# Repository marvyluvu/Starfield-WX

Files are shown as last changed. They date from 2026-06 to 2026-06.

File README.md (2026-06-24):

<h1 align="center">StarField WX</h1>

starfield

<p align="center">
  <i>Portable Arduino‑powered dew‑risk weather station with LCD and LED halo.</i>
</p>

---

##  1. What is STARFIELD WX?

<p>
Starfield WX is a pocket-sized weather station that tells you when dew is about to become a problem for stargazing/ astrophotography.
</p>

---

##  2. Why did I make it?

<p>
I love being outside with my telescope, but because of where I live, I always end up with dew messing up my session before I could photograph anything. Starfield WX is my companion project for ORBTIZ. it can warn you about dew forming before it ruins your session.

---

##  3. How does it work?

The brains of the operation is the arduino uno. It:
- Reads temperature and humidity from a DHT11 module.
- Calculates an approximate dew point from those readings.
- Classifies dew risk (LOW, MEDIUM, HIGH) based on the spread between temperature and dew point.
- Shows live values on a 16×2 character LCD while auto‑cycling between temperature, humidity, and dew‑point screens.
- Uses a WS2812B LED halo as a status ring: green for low risk, orange for medium, red when dew is imminent.

---

##  4.Hardware schematic

<p>
You can view the full schematic for the ORBITZ PCB below.

The custom STARFIELD pcb plugs directly onto an Arduino Uno and breaks out all parts needed for weather station
</p>

key pins:
-  DHT11 data -> Arduino digital pin 2
-  WS2812B LED strip -> Arduino digital pin 6
-  1602 LCD (parallel) -> Arduino digital pins 7–12
-  Trimmer potentiometer -> LCD contrast
-  series resistors for the LCD backlight and LED strip data line

you can view the full schematic here.
STARFIELD schematic

---

##  5. How do you use it?

Power on the arduino uno via USB or a **5v** supply ( you can also power it using the usb hub on orbitz!!)

StarField WX boots, then starts cycling through three screens on the LCD:
  - Temperature in C
  - Relative humiditry in %
  - Dew point in C

The led halo color shows dew risk : green (low), orange ( medium), red (high).
when it turns red, conditions are close to the dew point and you should protect your optics or wrap up the session , unfortunately :( 

---
## 6. Assembly
Below is what the fully assembled design should look like.
1. Order all parts from the Starfield BOM.
2. Solder headers, resistors, the DHT11 module connector, LCD header, LED Strip header to the PCB.
3. Mount the potentiometer and adjust until the LCD text is clearly visible.
4. Attach the 1602 LCD to the enclosure using standoffs.
5. Cut the ws2812b strip to length and mount it arond the inside the top of the enclosure, then wire it to 5v, GND, and the data pin.
6. Insert the shield onto the Arduino Uno and secure the PCB into the enclosure.
7. Upload the code and enjoy!!

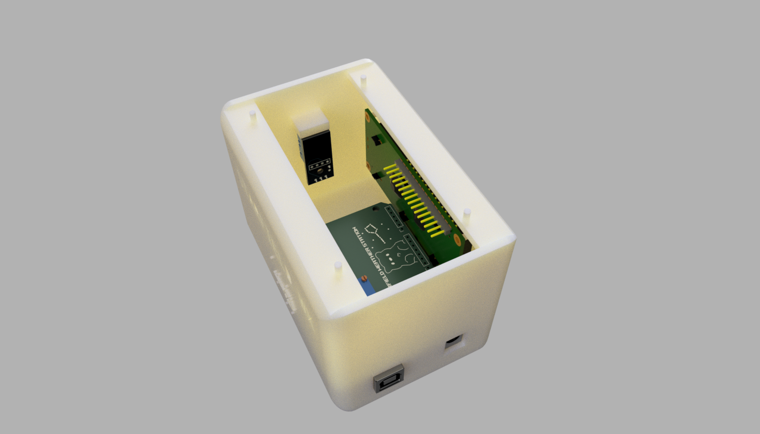
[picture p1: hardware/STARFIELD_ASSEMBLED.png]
STARFIELD enclosure interior


---

## 7. Firmware
The firmware is a single Arduino sketch that runs on the Uno

Features:

- Periodically reads DHT11 temperature and humidity
- computes dew point using a simple approximation formula
- cycle LCD screens every few seconds (temperature, humidty, dew point)
- computes dew risk catergory and updates the LED halo color

## how to flash
1. open firmware/starfield_wx.ino in the arduino IDE
2. select arduino uno as the board and choose the correct serial port
3. Install these libraries (DHT11, NEOPIXELS, LIQUID CRYSTALS) - (see [Arduino Library Installation Guide](https://docs.arduino.cc/software/ide-v1/tutorials/installing-libraries/) to know how to install libraries)
5. click upload.
6. after reseting, the splash screen appears, then live readings start
Feel free to tweak the threshold and LED colors to match your local climate and conditions

##  8. Images

<table>
  <tr>
    <td align="center">
      <strong>FINAL PCB SCREENSHOTS</strong><br><br>
      FINAL PCB SCREENSHOTS
    </td>
  </tr>
  <tr>
    <td align="center">
      <strong>PCB</strong><br><br>
      PCB
    </td>
  </tr>
  <tr>
    <td align="center">
      <strong>FINAL BUILD</strong><br><br>
      FINAL BUILD
    </td>
  </tr>
</table>

##  8. Bill of Materials (BOM)

The full detailed BOM is included in this repository:

- [[`/STARFIELD_BILL_OF_MATERIALS.csv`](https://github.com/marvyluvu/Starfield-WX/blob/69a2b140c6205f69048c935fe2e7507fc950f91d/hardware/STARFIELD_BOM.csv)

You can open this file in Excel, Google Sheets, or any spreadsheet tool.
It includes part names, descriptions, quantities, prices, and direct purchase links.

Key components

### Full BOM (summary)

### Full BOM (summary)

| Product name | Description | Qty | Unit price | Link |
|---|---|-----|---|---|
| Arduino Uno | Main microcontroller board | 1 | dh30.90 | [Amazon](https://www.amazon.ae/UNO-ATmega328P-Development-Straight-Developer/dp/B07PFCGYRS/) |
| WS2812B RGB STRIP | led halo indicator | 1 | dh3.75 | [AliExpress](https://ar.aliexpress.com/item/1005005537967685.html) |
| jumper cables | for connecting components internally | 1 | dh12.45 | [AliExpress](https://www.aliexpress.com/ssr/300000512/BundleDeals2?productIds=1005003641187997%3A12000026613929397) |
| STARFIELD custom pcb | main board | 1 | dh108.67 | JLCPCB |
| MALE HEADERS | LED , DHT11 PINS | 1 | dh3.75 | [AliExpress](https://ar.aliexpress.com/item/1005001514058091.html) |
| DHT11 MODULE | HUMIDTY AND TEMP SENSOR | 1 | dh17.48 | [AliExpress](https://ar.aliexpress.com/item/1005012263106656.html) |
| 1602A LCD Display | Main Display | 1 | dh65.88 | [Amazon](https://www.amazon.ae/naughtystarts-Character-Controller-Blacklight-Compatible/dp/B0B1QFDJ3Y/) |
| Trimmer potentiometer | Controls display contrast (3296W-103 10K) | 1 | dh10.90 | [AliExpress](https://ar.aliexpress.com/item/1005012099171886.html) |
| 220 OHM RESISTOR | lcd backlight resistor 220 OHM | 1 | dh3.75 | [AliExpress](https://ar.aliexpress.com/item/1005004002774546.html) |
| 330 OHM RESISTOR | led strip resistor 330 OHM | 1 | dh3.75 | [AliExpress](https://ar.aliexpress.com/item/1005004002774546.html) |

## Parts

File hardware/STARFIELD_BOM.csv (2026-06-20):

Product name | Product description | Quantity | Product unit price | Product Total price | Product running total. | Product link
Arduino Uno | Microcontroller | 1 | dh30.90 | dh30.90 | dh30.90 | https://www.amazon.ae/UNO-ATmega328P-Development-Straight-Developer/dp/B07PFCGYRS
Ws2812b RGB STRIP | led halo indicator | 1 | dh3.75 | dh3.75 | dh34.65 | https://ar.aliexpress.com/item/1005005537967685.html?curPageLogUid=1lvdTaLHOCXD
jumper cables | for connecting components internally | 1 | dh12.45 | dh12.45 | dh47.10 | https://www.aliexpress.com/ssr/300000512/BundleDeals2?productIds=1005003641187997%3A12000026613929397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
STARFIELD custom pcb | main board | 1 | dh108.67 | dh108.67 | dh155.77 | JLCPCB
MALE HEADERS | LED , DHT11 PINS | 1 | dh3.75 | dh3.75 | dh159.52 | https://ar.aliexpress.com/item/1005001514058091.html?curPageLogUid=lK0JHyx6snaf
DHT11 MODULE | HUMIDTY AND TEMP SENSOR | 1 | dh17.48 | dh17.48 | dh177.00 | https://ar.aliexpress.com/item/1005012263106656.html?curPageLogUid=ZAkdCPA11OTj
1602A LCD Display | Main Display | 1 | dh65.88 | dh65.88 | dh242.88 | https://www.amazon.ae/naughtystarts-Character-Controller-Blacklight-Compatible/dp/B0B1QFDJ3Y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
Trimmer potentiometer | Controls display contrast (Resistance: 3296W-103 10K 5pcs ) | 1 | dh10.90 | dh10.90 | dh253.78 | https://ar.aliexpress.com/item/1005012099171886.html?curPageLogUid=e5fHMHjDMXnP
220 OHM RESISTOR | lcd backlight resistor 220 OHM | 1 | dh3.75 | dh3.75 | dh257.53 | https://ar.aliexpress.com/item/1005004002774546.html?curPageLogUid=g365oloRU88X
330 OHM RESISTOR | led strip resistor 330 OHM | 1 | dh3.75 | dh3.75 | dh261.28 | https://ar.aliexpress.com/item/1005004002774546.html?curPageLogUid=g365oloRU88X
M3 SCREW SET | mounting pcb, screen and everything else 50 pcs 3mm | 1 | dh5.00 | dh5.00 | dh266.28 | https://ar.aliexpress.com/item/33028169759.html?curPageLogUid=FOQQuqUMxISX
m3 BRASS screw inserts | mounting pcb and screen 25pcs M3(OD 4.2mm) 3mm long | 1 | dh3.75 | dh3.75 | dh270.03 | https://ar.aliexpress.com/item/1005008644449489.html?curPageLogUid=LHAMBBpKP3UV
acrylic top lid | acrylic top for the enclosure 100x100x2mm | 1 | dh5.85 | dh5.85 | dh275.88 | https://ar.aliexpress.com/item/1005008256425253.html?curPageLogUid=aXpQDZTxyX5o
3d printing costs | enclosure printing in resin | 1 | dh47.38 | dh47.38 | dh323.26 | JLC3DP
 |  |  |  | TOTAL FOR EVERYTHING | dh323.26
 |  |  |  | IN USD | 88.01$

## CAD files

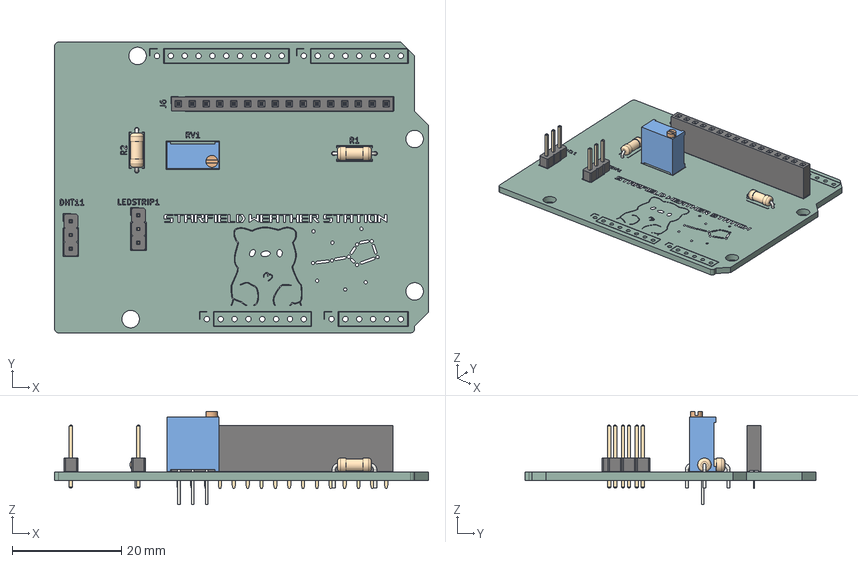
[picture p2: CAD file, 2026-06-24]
enclosure/STARFIELD PCB.step
68.6 x 53.3 x 17.1 mm
PinHeader_1x03_P2.54mm_Vertical x 2
Potentiometer_Bourns_3296W_Vertical
PinSocket_1x16_P2.54mm_Vertical
R_Axial_DIN0207_L6.3mm_D2.5mm_P7.62mm_Horizontal x 2
starfield_silkscreen
starfield_PCB

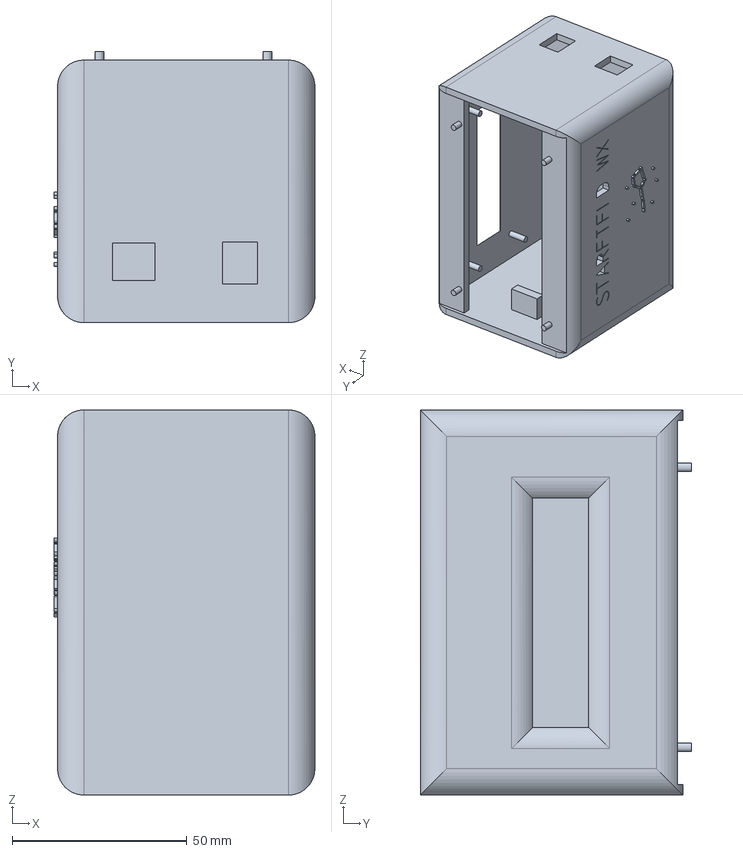
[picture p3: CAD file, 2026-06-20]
enclosure/enclosure.step
74.5 x 77.5 x 110.0 mm

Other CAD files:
enclosure/enclosure.f3d
enclosure/enclosure.stl

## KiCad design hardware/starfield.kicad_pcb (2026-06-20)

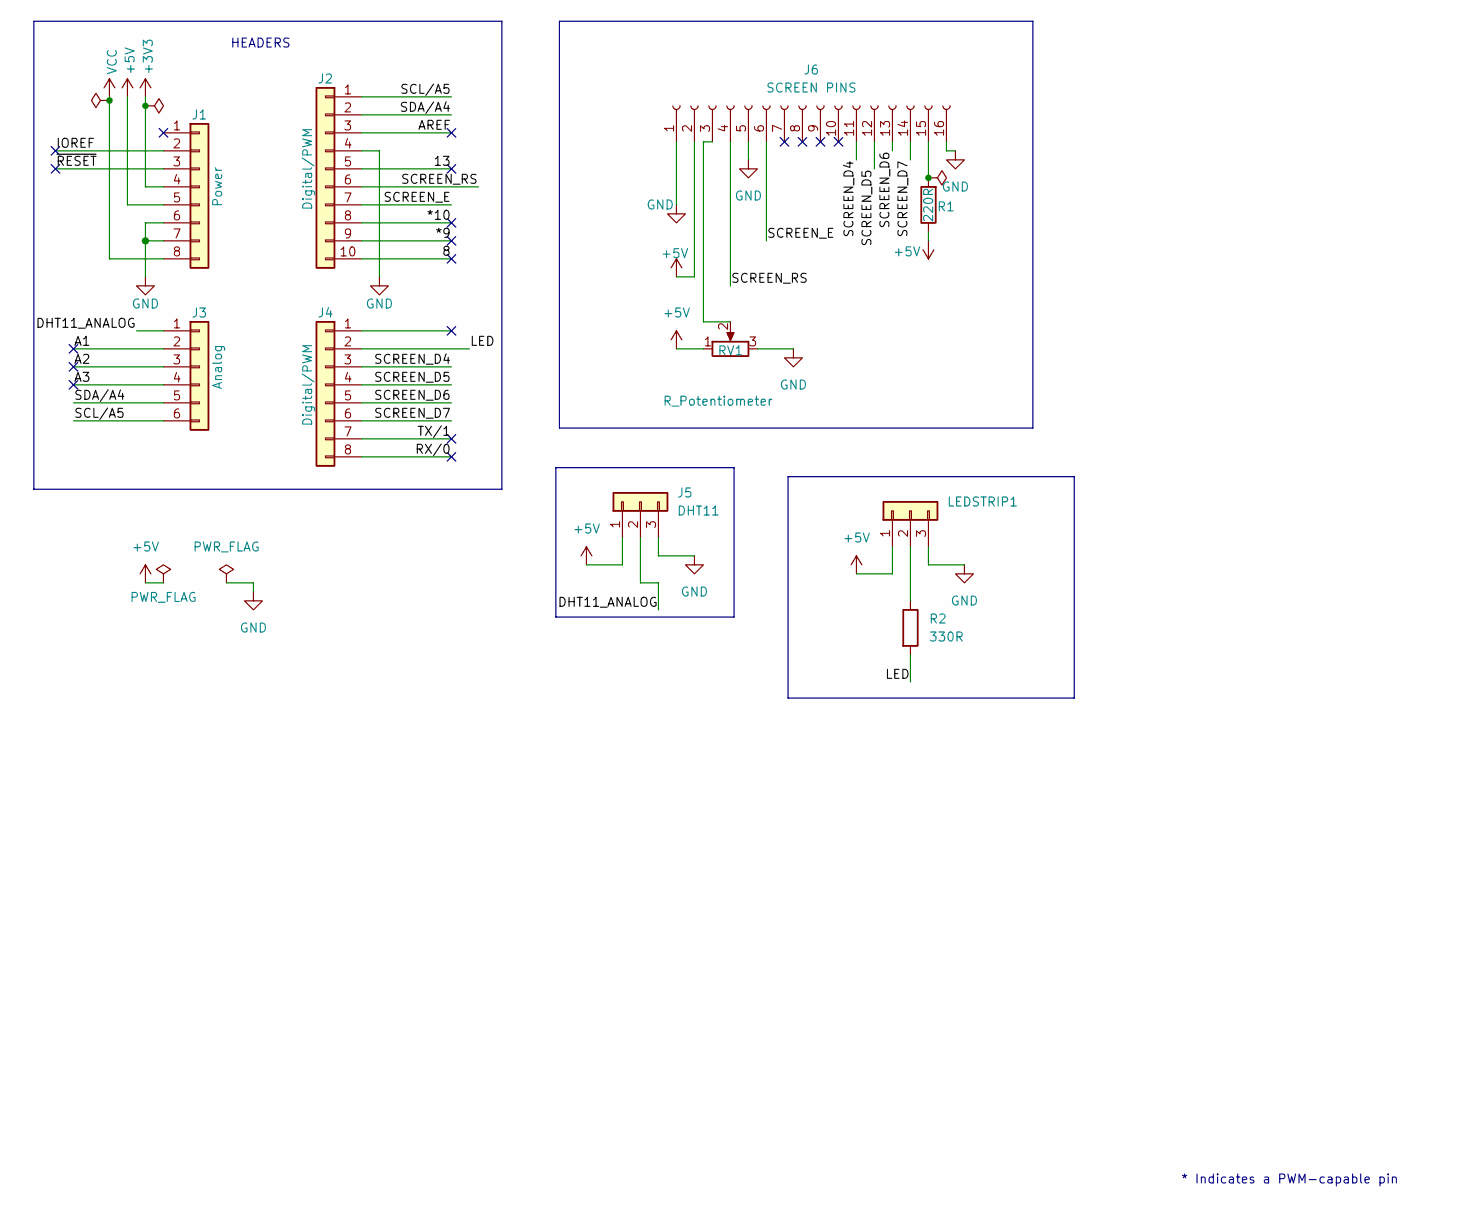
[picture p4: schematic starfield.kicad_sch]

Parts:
J1: Power; PinSocket_1x08_P2.54mm_Vertical
J2: Digital/PWM; PinSocket_1x10_P2.54mm_Vertical
J3: Analog; PinSocket_1x06_P2.54mm_Vertical
J4: Digital/PWM; PinSocket_1x08_P2.54mm_Vertical
J5: DHT11; PinHeader_1x03_P2.54mm_Vertical
J6: SCREEN PINS; PinSocket_1x16_P2.54mm_Vertical
LEDSTRIP1: LEDSTRIP1; PinHeader_1x03_P2.54mm_Vertical
R1: 220R; R_Axial_DIN0207_L6.3mm_D2.5mm_P7.62mm_Horizontal
R2: 330R; R_Axial_DIN0207_L6.3mm_D2.5mm_P7.62mm_Horizontal
RV1: R_Potentiometer; Potentiometer_Bourns_3296W_Vertical

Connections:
+3V3: J1.4
+5V: J1.5, J5.1, J6.2, LEDSTRIP1.1, R1.1, RV1.1
/8: J2.10
/13: J2.5
/*9: J2.9
/*10: J2.8
/A1: J3.2
/A2: J3.3
/A3: J3.4
/AREF: J2.3
/DHT11_ANALOG: J3.1, J5.2
/IOREF: J1.2
/LED: J4.2, R2.2
/RX/0: J4.8
/SCL/A5: J2.1, J3.6
/SCREEN_D4: J4.3, J6.11
/SCREEN_D5: J4.4, J6.12
/SCREEN_D6: J4.5, J6.13
/SCREEN_D7: J4.6, J6.14
/SCREEN_E: J2.7, J6.6
/SCREEN_RS: J2.6, J6.4
/SDA/A4: J2.2, J3.5
/TX/1: J4.7
/~RESET: J1.3
GND: J1.6, J1.7, J2.4, J5.3, J6.1, J6.5, J6.16, LEDSTRIP1.3, RV1.3
unnamed: J6.3, RV1.2
unnamed: J6.15, R1.2
unnamed: LEDSTRIP1.2, R2.1
VCC: J1.8

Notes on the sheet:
HEADERS
* Indicates a PWM-capable pin

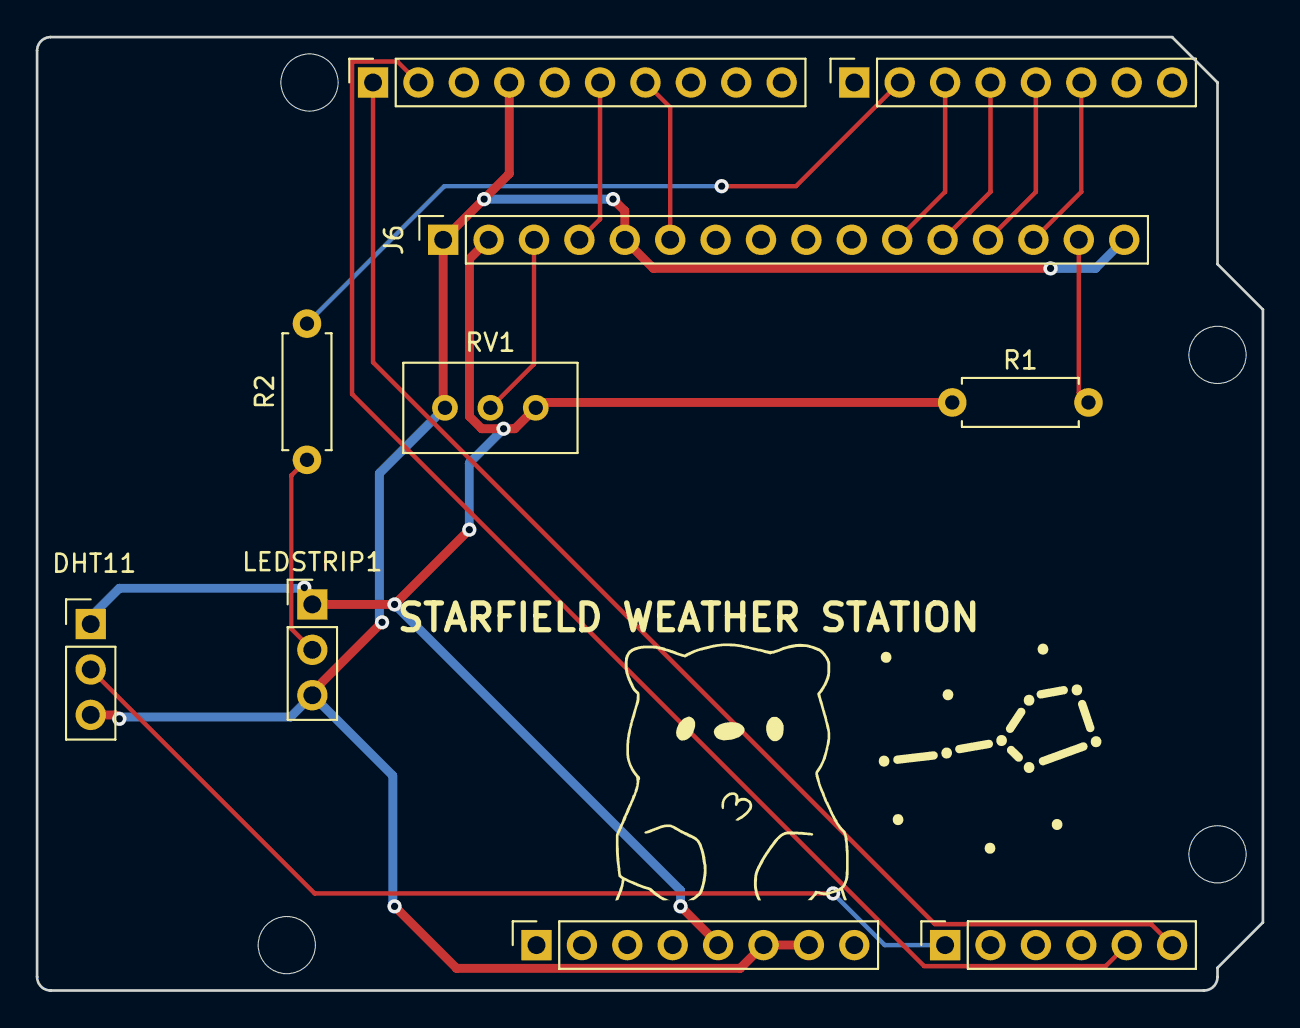
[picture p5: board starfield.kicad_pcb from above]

Board: 2 copper layers, 68.6 x 53.3 mm, 14 parts (0 on the bottom side), 15 nets.

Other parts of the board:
MH1, MH2, MH3, MH4: MountingHole_3.2mm

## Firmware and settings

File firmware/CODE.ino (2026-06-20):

#include <DHT.H>
#include <LiquidCrystal.h>
#include <Adafruit_NeoPixel.h>


#define DHTPIN 2
#define DHTTYPE DHT11
DHT dht(DHTPIN, DHTTYPE);

LiquidCrystal lcd(7, 8, 9, 10, 11, 12);
#define NEOPIXEL_PIN 6
#define NUM_PIXELS 16
Adafruit_Neopixel pixels(NUM_PIXELS, NEOPIXEL_PIN, NEO_GRB + NEO_KHZ800);

enum ScreenMode {
    SCREEN_TEMP,
    SCREEN_HUM,
    SCREEN_DEW,

};

ScreenMode currentScreen = SCREEN_TEMP;
unsigned long lastScreenChange = 0;
const unsigned long SCREEN_INTERVAL = 4000; // ms

unsigned long lastRead = 0;
const unsigned long READ_INTERVAL = 2000; //ms

float tC = NAN;
float h = NAN;
float dew = NAN;
String dewRisk = "UNKNOWN";
unint32_t riskColor = 0;

float computeDewPoint(float tempC, float humidity) {
    if (humidity <= 0 || humidity > 100 || isnan(tempC)) return NAN;
    float a = 17.27;
    float b = 237.7;
    float alpha = ((a * tempC) / (b + tempC)) + log(humidity / 100.0);
    float dp = (b * alpha) / (a - alpha);
    return dp;

}

void computeDewRisk() {
    if (isnan(tC) || isnan(dew)) {
        dewRisk = "NO DATA";
        riskColor = pixels.Color(0,0,0);
        return;
    }

    float spread = tC - dew;

    if (spread > 3) {
        dewRisk = "LOW";
        riskColor = pixels.Color(0, 150, 0);
    } else if (spread > 1.0){
        dewRisk = "MEDIUM";
        riskColor = pixels.Color(255, 140, 0);
    } else {
        dewRisk = "HIGH";
        riskColor = pixels.Color(200, 0 , 0)
    }
}
void showRiskOnHalo() {
    for (int i = 0; i < NUM_PIXELS; i++){
        pixels.setPixelColor(i, riskColor);
    }
    pixels.show();
}

void updateLCD() {
    lcd.clear();
    lcd.setCursor(0,0);
    lcd.print("STARFIELD WX")

    lcd.setCursor(0,1);
    switch (currentScreen) {
        case SCREEN_TEMP:
        lcd.print("T: ");
        if (isnan(tC)) lcd.print("--.-");
        else {
            lcd.print(tC, 1);
            lcd.print((char)223);
            lcd.print("C");
        }
        lcd.print(" ");
        lcd.print("R: ");
        lcd.print(dewRisk);
        break;

    case SCREEN_HUM:
    lcd.print("H: ");
    else {
        lcd.print(h, 1);
        lcd.print("%");

    }
    lcd.print(" ");
    lcd.print("R:")
    lcd.print(dewRisk);
    break;

    case SCREEN_DEW:
      lcd.print("DEW: ");
      if (isnan(dew)) lcd.print("--.-");
      else {
        lcd.print(dew, 1);
        lcd.print((char)223);
        lcd.print("C");
      }
      lcd.print(" ");
      lcd.print("R:");
      lcd.print(dewRisk);
      break;
  }
}

void setup() {
    dht.begin();
    lcd.begin(16, 2);
    pixels.begin();
    pixels.clear();
    pixels.show();
    lcd.clear();
    lcd.setCursor(0,0);
    lcd.print("STARFIELD");
    lcd.setcCursor(0, 1);
    lcd.print("Booting...");
    delay(1500);

}
void loop() {
    unsigned long now = millis();

    if (now - lastRead >= READ_INTERVAL){
        lastRead = now;
        float newH = dht.readHumidity();
        float newT = dht.readTemperature();

        if (!isnan(newH) && !isnan(newT)) {
            h = newH;
            tC = newT;
            dew = computeDewPoint(tC, h);
            computeDewRisk();
            showRiskOnHalo();
        }
    }
  if (now - lastScreenChange >= SCREEN_INTERVAL) {
    lastScreenChange = now;

    if (currentScreen == SCREEN_TEMP)      currentScreen = SCREEN_HUM;
    else if (currentScreen == SCREEN_HUM)  currentScreen = SCREEN_DEW;
    else                                   currentScreen = SCREEN_TEMP;

    updateLCD();
  }
}

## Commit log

2026-06-20 Rename STARFIELD ASSEMBLED.png to STARFIELD_ASSEMBLED.png
2026-06-20 Rename STARFIELD BOM.csv to STARFIELD_BOM.csv
    [STARFIELD_BOM.csv]
2026-06-20 Rename ORBITZ - STARFIELD BOM.csv to STARFIELD_BOM.csv
    [STARFIELD_BOM.csv]
